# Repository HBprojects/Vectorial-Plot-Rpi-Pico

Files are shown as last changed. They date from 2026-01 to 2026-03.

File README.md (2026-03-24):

# Vectorial Reconstruction of an Electric Heart Vector in Saline Solution
This project implements a minimal analog front-end and software reconstruction algorithm to track a dipole vector immersed in saline solution. Drawing from the Einthoven triangle and its bipolar leads, maps electric potential to a real-time vectorial representation, similar how ECG devices take cardiac signals.
<p align="center">
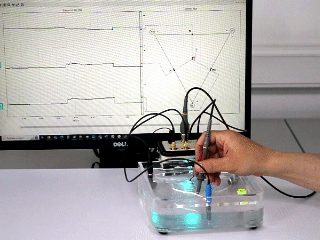
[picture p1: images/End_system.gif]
  
  
## 1. Motivation and context
The conduction and acquisition of biopotentials are non-observable phenomena, mastering these concepts typically requires a deep dive into abstract physiological theory. This project provides a tangible, real-time bridge between theory and practice.
By measuring potential differences induced by a hand probe within a conductive saline medium, this software calculates and graphically reconstructs a single dipole orientation and magnitude in real time. This approach transforms invisible electrical fields into an intuitive visual format.
## 2. System Overview
The physical setup mimics a standard **three-lead frontal plane EKG configuration** (RA, LA, LL) within a controlled environment.
### 2.1 Physical Configuration
- **The Medium:** A 500mL container filled with a 0.9% saline solution or a salt-water mixture.
- **The Electrodes:** Three terminal electrodes, which can be made from peeled wire, are placed in an equilateral triangle around the perimeter of the container.
- **Peripheral Spacing:** Peripheral electrodes are ideally separated by 120 to 150 mm.
### 2.2 The Dipole Source
- **Anode:** A wire is placed at the center of the container with a small exposed portion. This allows the system to show positive and negative voltages at the center of the projection lines.
- **Cathode (Probe):** An oscilloscope probe serves as the hand movable electrode. A wire with a 300Ω series resistor can also be used for testing.
- **Power:** The system is powered with 5V DC relative to the central terminal. This configuration is specifically chosen to minimize cathode corrosion within the electrolytic solution.
### 2.3 Data Acquisition & Processing
While high-performance differential ADCs or microcontrollers like the NXP K64F are recommended for precision, this repository provides a setup for easy testing using a Raspberry Pi Pico. The signal is pre-amplified by instrumentation amplifiers, biased at mid-supply, and processed in software to remove offset and gain before being streamed as comma-separated numeric values for real-time plotting.
## 3. Repository Structure
```text
project/
│
├── firmware/
│   └── Vecto_pico.py              # Micropython program for Raspberry Pi Pico
│   └── demo_signal_pico.py		   #Fast test of Pico board and graph program
│   └── VECTO2_MK64F12_Project.hex # Binary file for FRDM K64F board
├── images/	
├── kicad/				             # Circuit files
├── software/
│   └── vecto_graph.py		 	    # Real-time plotting via Python and Matplotlib
└── README.md
```
## 4. Implementation Architecture
The system is designed to provide high-fidelity signal acquisition while maintaining a simple interface for real-time analysis.
- **Analog Front-End;** True differential sensing to capture signals before ADC quantization.
- **Digitization;** The Raspberry Pi Pico ADC serves as a digitizer. A more reliable and precise version using the NXP K64F microcontroller.
- **Visualization;** A Python sketch allows for interaction with the circuit and real-time signal plotting.
### 4.1 Components
The following components are required to replicate the basic experimental setup:
| Qty | Component | Notes |
|:---:|:---|:---|
|2| INA128 instrumentation amplifiers | See schematic |
|1| Raspberry Pi Pico V2 | 
|12| Resistors (1% preferred) | See schematic |
|4| Decoupling and filtering capacitors | See schematic |
|1| Isolated 5V Lab power supply | Also tested with SWM12-5-N adapter |
|1| 1X Oscilloscope probe | Also tested with a wire with 300 ohm series resistor |
|1| 500mL 0.9% saline solution | Also tested with salt-water mixture |
|1| Low profile plastic container | Peripheral electrodes separated between 120 to 150 mm|
---
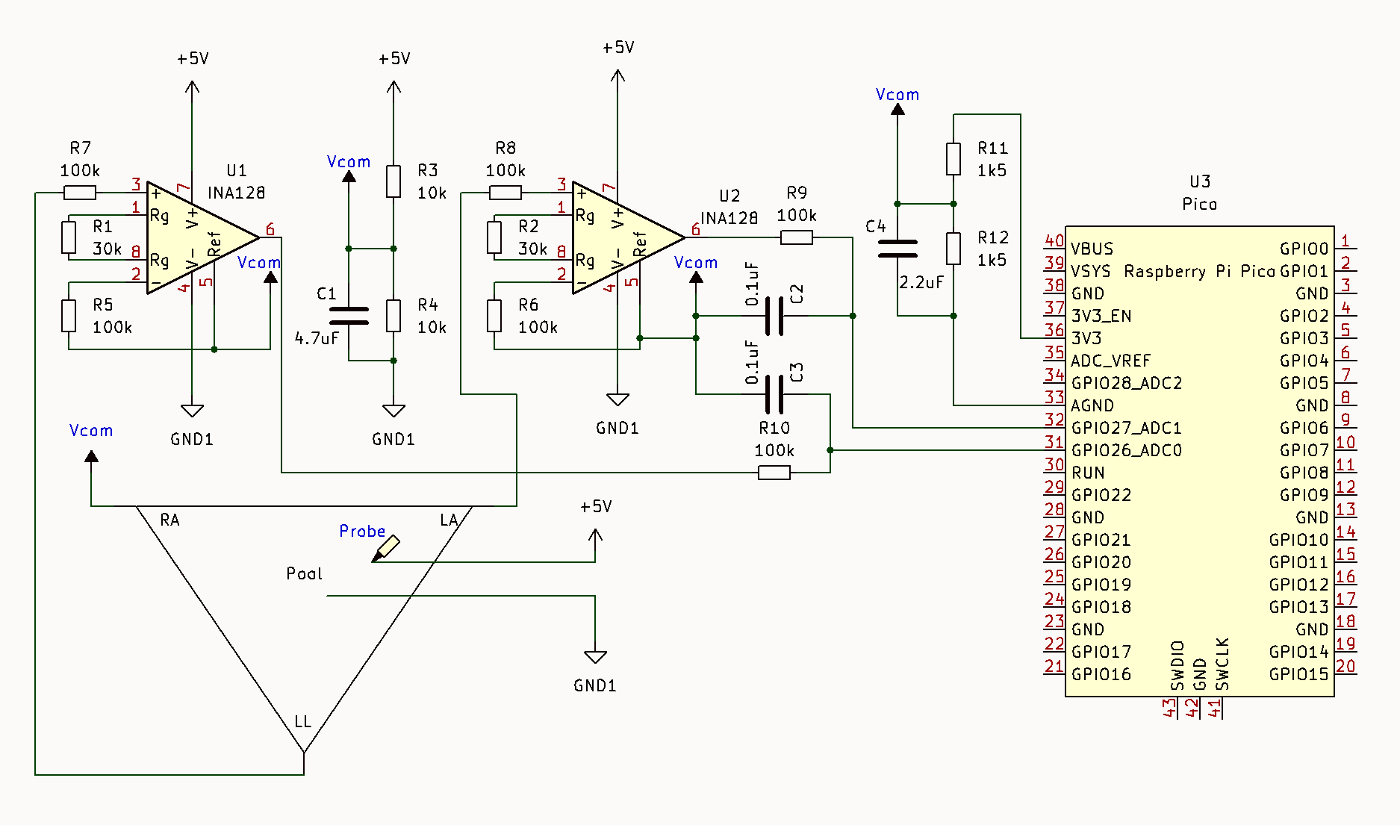
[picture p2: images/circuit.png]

The following components are required to replicate the improved performance setup version based on (FRDM K64F board):
| Qty | Component | Notes |
|:---:|:---|:---|
|1| MAX6018 | Voltage reference | See schematic |
|1| MAX4053 | Multiplexer | See schematic |
|1| K64F Microcontroller | FRDM K64F Board |
|-| Decoupling and filtering capacitors | See schematic |
|1| power supply | SWM12-5-N adapter |
|1| ITX0505SA | DC-DC Converter |
|1| 1X Oscilloscope probe | Also tested with a wire with 300 ohm series resistor |
|1| 500mL 0.9% saline solution | Also tested with salt-water mixture |
|1| Acrylic plastic container | Peripheral electrodes separated between 120 to 150 mm|
---

### 4.2 Power Domains & Grounding
 - **Analog Domain**: INA128 powered from an **isolated 5V source**, Two operational amplifiers couple the LI and LII signals, by the Kirchoff’s voltage law LI+LIII=LII, which allows the system to calculate LIII, However the measurement of the third value allows the system to reduce the zero error.
 - **Digital domain**: Pico powered from USB- Improves noise immunity
 - **Reference coupling**: Single-point connection between:
 - INA128 `REF`5 V mid-voltage 
 - Pico 3.3V mid-voltage
This architecture minimizes ground loops and digital noise injection and centers ADC measurements.
### 4.3 Gain Configuration
INA128 gain is defined by:
$G = 1 + 50kΩ/R_G$
Current implementation:
- Gain ≈ **2.6**
- Optimized for ±0.3 V input signals
- Ensures ADC full-scale utilization without saturation
## 5. Firmware (Raspberry Pi Pico_MicroPython, hex file for K64F)
Two independent programs facilitate the implementation of the system.
- **vecto_pico.py** Streams three values ( LI. LII, LIII) obtained by the ADC.
- **demo_signal_pico.py** A sketch for rapid testing of communication and visualization program. Load the sketch to the Raspberry Pi Pico and a demo signal are streamed by the USB port to the visualization program.
### 5.1 Acquisition Strategy
- Two ADC channels sampled independently
- Oversampling with averaging
- Offset removal is managed via a shared reference.
### 5.2 Pico Firmware Code
```python
from machine import ADC
import time
# --- Configuration ---
VREF = 3.3
VMID = 1.4 #VREF/2 A bit less improve zero error.
GAIN = 2.6 #The analog gain in the instrumentation amplifier.
```
- Analog and digital supplies are isolated except for a **shared reference point**
- Very high input impedance → suitable for **low-power sensors**
- To change the signal register speed, press ‘m’ in the keyboard in the graphic program.
- The time scale is the same, that allows to draw waveforms more easy, for example a wave of 100mS period can be draw in 1S.
### 5.3 Data Output Format
Each serial line contains three comma-separated floating-point values: 
Raspberry Pi Pico: DI, DII, DIII.
K64F: DI, DII, DIII,Calculated AvR, Calculated AvF, Calculated AvL, Sample_time (mS).
```text
Example:
Raspberry Pi Pico: 
0.01234, -0.01022,1.81200
K64F: 
0.01234, -0.01022,1.81200,0.02545,0.78459,0.89156,0.84100
```
### 5.4 Demo signal program.
The program continuously streams a previously recorded ECG signal to the host graphical application through a USB serial port, allowing the firmware and host program to be tested without difficulty.
```python
# --- Parameters ---
SCALE_FACTOR = 0.000435 #This value converts the table values to mS
TARGET_POINTS = 680 #Adjust the time scale, 
```
The **target points** parameter keeps the ECG signal within a normal scale, typically ranging between 600 and 700 points. This is because the table contains a fixed number of points, which must be adapted to the amount of data that can be effectively represented graphically.
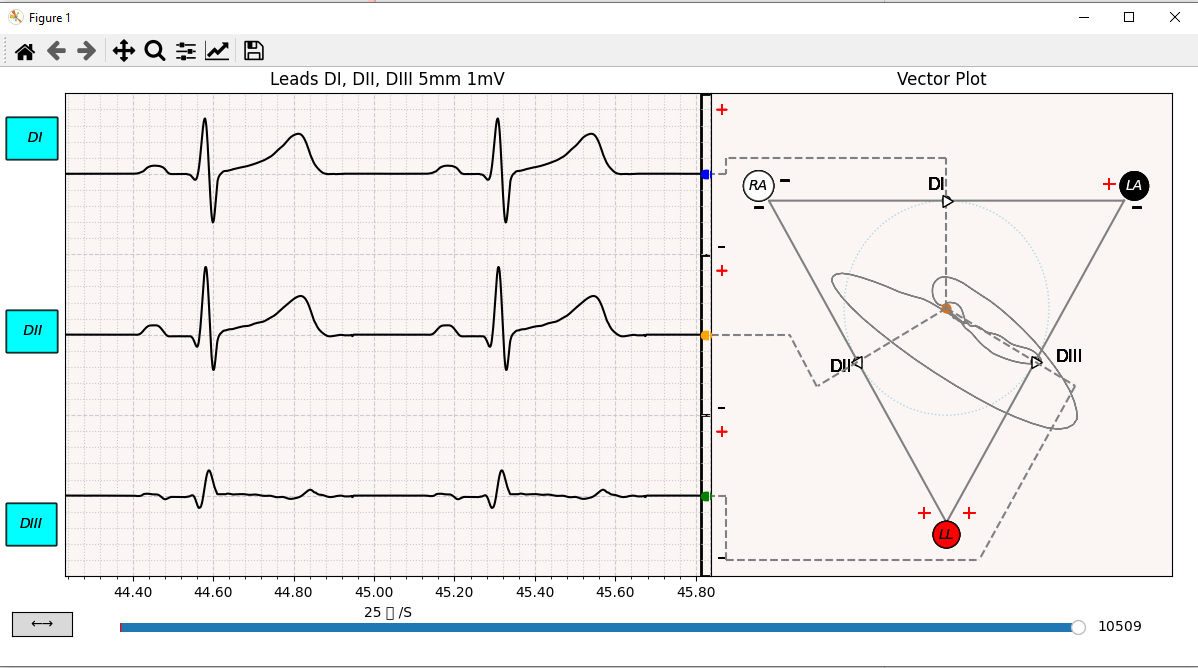
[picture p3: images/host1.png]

### 5.5 Animation Speed vs. Time Scale
The delay time parameter allows you to slow down the signal animation to observe vector behavior more clearly.
- **Animation Speed:** Adjusting the delay does not change the actual time scale of the signal.
- **Accuracy:** For example, if a signal period is 0.75s, the scale will always display 0.75s regardless of the animation speed. This ensures that any captured or "printed" signal maintains its physical temporal accuracy.
```python
# --- Parameter ---
# Adjust this value (e.g., between 5-50) to slow the animation
utime.sleep_ms(5)
``` 
### 5.6 Getting Started
- Flash the Pico: Use Thonny to upload the demo_signal_pico.py sketch to your Raspberry Pi Pico.
- Configure the Host: Open the host script vecto_graph.py in a text editor and update the serial port number to match your Raspberry Pi Pico’s port.
- Updating Parameters: To apply new changes to the Pico, close the host program, update the code, and re-upload the sketch to the board.
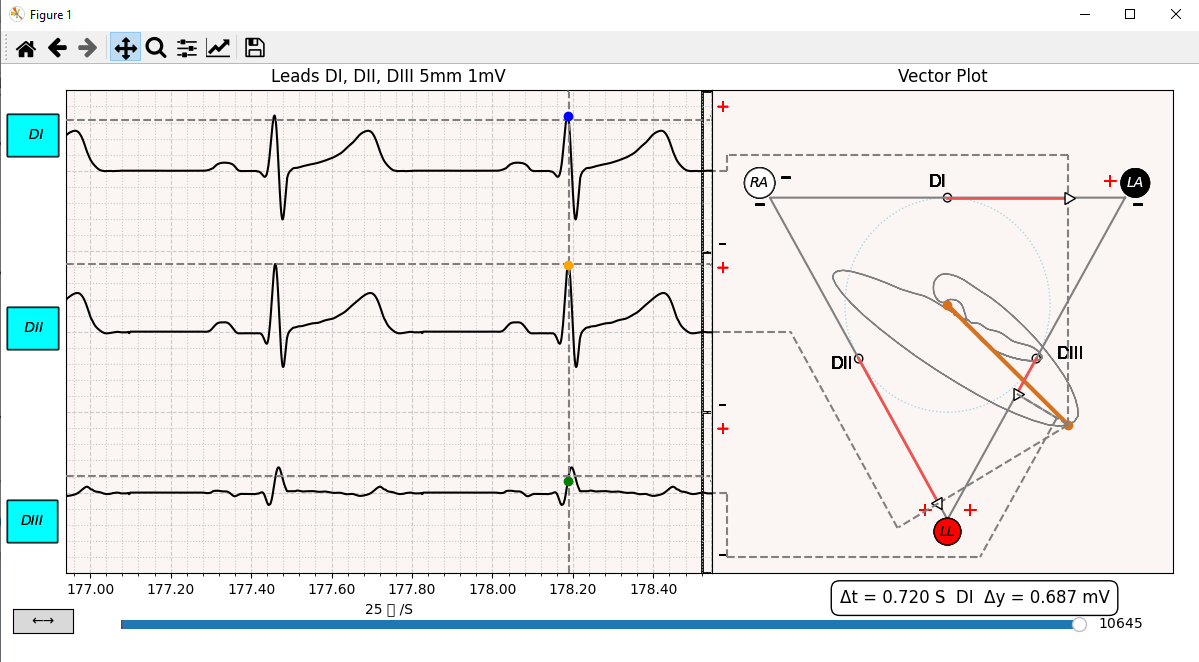
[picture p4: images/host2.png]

### 5.7. Interacting with the Graph
- **Pause:** Press the "P" key while the signal is running to pause the animation.
- **Inspection:** Move your mouse over the signal profile. A crosshair will track your pointer, and the vector graph will update dynamically to reflect the values at that specific point.
- **Measurement:** Click anywhere on the three signals to set a reference point.
 - The bottom-right corner of the screen will display two numerical values.
 - Click a second time at a different location to calculate the amplitude and time lapse (Δt) between the two selected points.

## 6. Host-Side Visualization (Python)
### 6.1 Features
- High-baud serial acquisition and circular buffering for real-time plotting.
- Data history retention for 5 seconds with a scrollable timeline.
- Interactive controls: Pause/resume via keyboard ('p') and grid-based signal inspection.
- Multi-channel and vector visualization.
### 6.2 Implementation
Using pyserial, numpy, matplotlib, and FuncAnimation. It continuously reads the serial output and maintains a fixed-length real-time window for inspection.
The script:
- Continuously reads Pico serial output
- Maintains a fixed-length real-time window
- Allows retrospective inspection of stored data
- Supports interactive control via keyboard
## 7. Experimental Performance
Parameter	Observed
Input range	±0.3 V
CMRR	~90 dB (INA128)
Effective resolution	~10–11 ENOB
ADC sampling stability	Good (with averaging)
Noise sensitivity	Dominated by reference stability
## 8. Limitations
- Pico ADC is not differential
- Overall ENOB limited by RP2040 ADC
- INA128 is not rail-to-rail amplifier.
- Requires careful reference grounding
Adding DC-DC converter before the polarization electrodes and a precision voltage reference improves the noise reduction the K64F firmware includes 60Hz Notch filter.
## 9. Next Steps
The second part of this project consists of:
Python host-side excecutable code.
Bioamplified version.
Zero correction and central terminal software.
This will be documented separately.
## 10. Authors
- Profesor Diana Patricia Amador PhD.
- Profesor William Ricardo Rodríguez PhD.
- Hernan Bernal Mechanical Designer.

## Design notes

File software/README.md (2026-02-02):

# Real-Time Serial ECG Visualization Software
This software acquires 3-channel ADC signals (Simulated ECG) from a microcontroller over a serial connection, displays them in real time, allows pause/scroll/inspection, computes a heart vector, and saves synchronized data for offline analysis.
Designed for research and laboratory use.
## 1. Quick Start
Requirements
-	Python 3.x
-	NumPy
-	Matplotlib
-	PySerial
-	Microcontroller streaming ADC data via serial
### Run
python python vecto_graph.py
## 2. Critical Configuration (Must Read)
### 2.1 Serial Port
Set the correct serial port before running:
ser_port = 'COM10'  # Change to your port
Examples:
- Windows: COM3
-	Linux: /dev/ttyUSB0
-	macOS: /dev/cu.usbmodemXXXX
### 2.2 Expected ADC Channels (Firmware Match)
Inside read_serial_data() (≈ line 484):
if len(values) == 3:
-	Raspberry Pi Pico firmware → == 3
-	K64F firmware → replace with > 4
This must match the firmware output, or data parsing will fail.
## 3. Keyboard Controls (Core Usage)
| Key | Action | Notes |
|:---:|:---|:---|
|1| Isolated 5V Lab power supply | Also tested with SWM12-5-N adapter |
|a| Start ADC streaming | Active by default |
|p|	Pause / resume acquisition | Enables scrolling through previously recorded data |
|← / →|	Scroll data | (paused only) |
|j|	Save visible data window | numpy format .npy (paused only) |
|r|	Start recording | Only in K64F firmware, need a MicroSD card |
|d|	Dumie recorded signal | (Not paused) |
|z|	Zero offsets |In K64F firmware only |
|t|	Tune / calibration command | Only in K64F firmware |
|m|	Change actual speed | Fast by default |
## 4. Core Function (Must Understand)
on_key(event)
Handles all user interaction:
-	Controls pause/resume logic
-	Sends commands to the microcontroller
-	Enables data scrolling
-	Extracts, scales, and saves 3-channel data to .npy
This function defines how the user operates the software.
## 5. Typical Workflow
-	Set serial port
-	Connect microcontroller
-	Run the script
- Press p to pause
- Scroll and inspect data
- Press j to save
- Press p to continue in real time mode
- Press d to stream the demo signal (firmware)
## 6. Performance Functions
-	init() – Initializes figures, axes, buffers, and event handlers.
-	format_func() – Formats axis tick labels.
-	update_xspeed() – Changes plot scrolling speed.
-	update_slider() – Syncs slider limits with stored data.
-	onmove() – Tracks mouse movement over the plot.
-	plot_on_click() – Extracts data at a clicked point.
-	handle_resize() – Maintains layout on window resize.
-	calc_heart_vector() – Computes vector representation from 3 channels.
-	calc_per_points() – Computes values at a specific cursor position.
-	update_axs() – Updates plots during animation frames.
## 7. Data Output
Saved File
-	seem_ath20.npy. "seem_ath20" change the name as needed  in program line 352
-	Shape: (1500, 3) by default
- Columns: Channel 1, Channel 2, Channel 3
Saved when pausing (p) then (j).
## 8. Notes
•	Assumes synchronized multi-channel data
•	Timing depends on firmware sampling
•	Intended for experimental and research use

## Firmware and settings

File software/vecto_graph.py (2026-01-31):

import sys
import serial
import numpy as np
import matplotlib.pyplot as plt
from numpy import cos, sin, pi
import matplotlib.animation as animation
from matplotlib.widgets import Button
from matplotlib.widgets import Slider
from collections import deque
from matplotlib.backend_bases import MouseEvent
from matplotlib.patches import Rectangle
from matplotlib.ticker import MultipleLocator, FuncFormatter

ser_port = 'COM10'  # Replace with your serial port
baud_rate = 230400  # Increase the baud rate if possible
timeout = 0.1  # Non-blocking mode

# Create a serial connection
ser = serial.Serial(ser_port, baud_rate, timeout=timeout)

side_lines_color = 'black'#'white'
triangle_color = 'gray'#'orange'
x1_facecolor = '#FBF5F3'#'#FBF5F3' '#FBF5F3'
x2_facecolor = '#FBF5F3'#'#FBF5F3''#154F61'
proy_linesColor = 'gray'#'green'
# Define the circle radius
radius = 1
value1 = 0.0
value2 = 0.0
value3 = 0.0
x_pos = 0.0
y_pos = 0.0

offset1 = 150#-530
offset2 = 50#-570
offset3 = -50#10

# Calculate the side length of the equilateral triangle circumscribed around the circle
side_length = 2 * radius * np.sqrt(3)

# Define the number of data points to display in the real-time plot
max_data_points = 1500#was 1500
spd_idx = 1
paused = False
is_over_plot = False
on_click_flag = False
count_mouse_pos = 0
mouseXpos = 1
xm_val = 0
# Initialize NumPy arrays to store data
full_x_data = np.zeros(max_data_points)  # Dynamically grow as needed
D1_data = np.zeros(max_data_points)  # Dynamically grow as needed
D2_data = np.zeros(max_data_points)  # Dynamically grow as needed
D3_data = np.zeros(max_data_points)  # Dynamically grow as needed

# Initialize a circular buffer for real-time plotting
x_data = np.zeros(max_data_points)
y1_data = np.zeros(max_data_points)
y2_data = np.zeros(max_data_points)
y3_data = np.zeros(max_data_points)
index = 0

# Define the width ratio (left plot is 1.5 times wider than the right plot)
left_width = 1.4
right_width = 1
# Create the figure and subplots
fig, (ax1, ax2) = plt.subplots(1, 2, figsize=(12, 6), gridspec_kw={'width_ratios': [left_width, right_width]})
#fig, (ax1, ax2) = plt.subplots(1, 2, figsize=(16, 10))

fig.tight_layout()
fig.subplots_adjust(top=0.956, left=0.054)# Remove space between subplots
fig.subplots_adjust(wspace=0.0)# Remove space between subplots
fig.subplots_adjust(bottom=0.15)

line1, = ax1.plot([], [], label="DI", color='black')
line2, = ax1.plot([], [], label="DII", color='black')
line3, = ax1.plot([], [], label="DIII", color='black')
# Set plot labels
ax1.set_title("Leads DI, DII, DIII 5mm 1mV")

# Define the expected X, Y-axis range
y1_min, y1_max = -100, 200
x1_min, x1_max = 0, max_data_points
ax1.set_ylim(y1_min, y1_max)
ax1.set_xlim(x1_min, x1_max)
ax1.set_facecolor(x1_facecolor)
ax1.set_aspect('auto')

crosshair_h = ax1.axhline(color='gray', linestyle='--')  # Horizontal line
crosshair_i = ax1.axhline(color='gray', linestyle='--')  # Horizontal line
crosshair_j = ax1.axhline(color='gray', linestyle='--')  # Horizontal line
crosshair_v = ax1.axvline(color='gray', linestyle='--')  # Vertical line
crosshair_h.set_visible(False)
crosshair_i.set_visible(False)
crosshair_j.set_visible(False)
crosshair_v.set_visible(False)

last_point1, = ax1.plot([], [], 'bo')  # blue dot for DI
actual_point1, = ax1.plot([], [], 'bo')  # blue dot for DI
last_point2, = ax1.plot([], [], 'o', color='orange')  # dot for DII
actual_point2, = ax1.plot([], [], 'o', color='orange')  # dot for DII
last_point3, = ax1.plot([], [], 'go')  #dot for DIII
actual_point3, = ax1.plot([], [], 'go')  #dot for DIII

# Define the vertices of the equilateral triangle
# One side will be horizontal at the top
angles = np.deg2rad([60, 180, 300])  # Vertices of the equilateral triangle
triangle_x = side_length * np.cos(angles) / np.sqrt(3)
triangle_y = side_length * np.sin(angles) / np.sqrt(3)

# Adjust to make sure the top side is horizontal
# Rotate -30 degrees to make the top horizontal
rotation_angle = -30  # Degrees to rotate counterclockwise
rotation_matrix = np.array([
    [np.cos(np.deg2rad(rotation_angle)), -np.sin(np.deg2rad(rotation_angle))],
    [np.sin(np.deg2rad(rotation_angle)),  np.cos(np.deg2rad(rotation_angle))]
])
rotated_triangle = np.dot(rotation_matrix, np.vstack((triangle_x, triangle_y)))

# Close the triangle path
triangle_x = np.append(rotated_triangle[0], rotated_triangle[0][0])
triangle_y = np.append(rotated_triangle[1], rotated_triangle[1][0])

# Precompute triangle side vectors and lengths for projection calculations
triangle_vectors = [(triangle_x[j+1] - triangle_x[j], triangle_y[j+1] - triangle_y[j]) for j in range(3)]

# Create a slider for scrolling through the data
ax_slider = plt.axes([0.1, 0.05, 0.8, 0.03])
slider = Slider(ax_slider, '', 0, 1, valinit=0, valstep=4)
slider.set_active(False)  # Slider inactive until paused

x2_min, x2_max = -2.3, 2.2
y2_min, y2_max = -2.5, 2
ax1.set_aspect('equal', adjustable='datalim')  # Keep square aspect ratio
ax2.set_xlim(x2_min, x2_max)
ax2.set_ylim(y2_min, y2_max) 
ax2.set_title("Vector Plot")
ax2.set_anchor('C') 

# Remove y-axis number values but keep grid lines
ax1.tick_params(axis='y', which='both', length=0)  # Remove tick marks
ax1.set_yticklabels([])  # Remove y-axis labels but keep ticks for the grid

# Draw the circle with radius 1
circle = plt.Circle((0, 0), radius, color='lightblue', fill=False, linestyle='dotted')
ax2.add_artist(circle)

#Draw origin circles
circ1 = plt.Circle((0, 1), 0.04, color='black', fill=False)
ax2.add_artist(circ1)
circ2 = plt.Circle((0.866, -0.5), 0.04, color='black', fill=False)
ax2.add_artist(circ2)
circ3 = plt.Circle((-0.866, -0.5), 0.04, color='black', fill=False)
ax2.add_artist(circ3)

# Plot the equilateral triangle with the top side horizontal
ax2.plot(triangle_x, triangle_y, color=triangle_color, lw=1.5)

# Add text labels to the corners of the triangle
ax2.set_facecolor(x2_facecolor)
ax2.set_xticks([])  # Remove x-axis ticks
ax2.set_yticks([])  # Remove y-axis ticks
#for spine in ax2.spines.values():
#Signal rectangles 
rect1 = Rectangle((0.985,  0.666), 0.02, 0.333, transform=ax1.transAxes, edgecolor='black', lw=2, fill=True, facecolor=x1_facecolor)
ax1.add_patch(rect1)
rect2 = Rectangle((0.985, 0.333), 0.02, 0.333, transform=ax1.transAxes, edgecolor='black', lw=2, fill=True, facecolor=x1_facecolor)
ax1.add_patch(rect2)
rect3 = Rectangle((0.985, 0.0), 0.02, 0.333, transform=ax1.transAxes, edgecolor='black', lw=2, fill=True, facecolor=x1_facecolor)
ax1.add_patch(rect3)


# Draw lines from the center of the triangle sides to the perpendicular intersection points
midpoints = [((triangle_x[i] + triangle_x[i + 1]) / 2,
              (triangle_y[i] + triangle_y[i + 1]) / 2) for i in range(3)]

mid_x, mid_y = midpoints[1]
                #proy_lines[j+1].set_data([px-0.4, mid_x-0.562], [py-0.23 , mid_y])
x2_min, x2_max = -2.3, 2.2
new_line_1, = ax2.plot([x2_min, x2_min+0.77], [-0.25, -0.25], color=proy_linesColor, linestyle='--') 
new_line_2, = ax2.plot([x2_min + 0.15, 0.318], [y2_min + 0.15, y2_min + 0.15], color=proy_linesColor, linestyle='--') 

new_point_ax2 = ((y2_max - y2_min)/6)+y2_min
new_line_3, = ax2.plot([x2_min + 0.15, x2_min + 0.15], [y2_min + 0.15, new_point_ax2], color=proy_linesColor, linestyle='--') 
new_line_4, = ax2.plot([x2_min + 0.15, x2_min], [new_point_ax2, new_point_ax2], color=proy_linesColor, linestyle='--') 

new_point_ax2 = y2_max - ((y2_max - y2_min)/6)
new_line_5, = ax2.plot([x2_min + 0.15, x2_min + 0.15], [y2_max - 0.6, new_point_ax2], color=proy_linesColor, linestyle='--') 
new_line_6, = ax2.plot([x2_min + 0.15, x2_min], [new_point_ax2, new_point_ax2], color=proy_linesColor, linestyle='--') 
#proy_lines[j].set_data([x_pos, y2_min], [py + 0.4, py + 0.4])

#trace, = ax2.plot([], [], '.-', lw=1, ms=2, color='lightblue', zorder=1)
trace, = ax2.plot([], [], '-', lw=1, ms=2, color='gray', zorder=1)
vector, = ax2.plot([], [], 'o-', lw=3, color='#D8711C', zorder=2)
perpendicular_lines = [ax2.plot([], [], color=proy_linesColor, linestyle='--')[0] for _ in range(3)]
proy_lines = [ax2.plot([], [], color=proy_linesColor, linestyle='--')[0] for _ in range(5)]

#connector_lines = [ax2.plot([], [], 'o-', lw=3, color=side_lines_color)[0] for _ in range(3)]

connector_lines = []
for _ in range(3):
    line, = ax2.plot(
        [], [], 
        '-',                       # just a solid line
        lw=2,
        color=side_lines_color,
        marker=(3, 1, 0),          # a 3‑sided marker (triangle), 0° initial
        markevery=[-1],            # only draw that marker at the *last* point
        markersize=10,             # arrow‑head size
        markerfacecolor='white',    # fill color (change as you like)
        markeredgecolor=side_lines_color
    )
    connector_lines.append(line)

time_template = 'time = %.1fs'
time_text = ax2.text(0.05, 0.9, '', transform=ax2.transAxes)

ax_button = plt.axes([0.01, 0.05, 0.05, 0.04])  # Position: [x, y, width, height]
button1 = Button(ax_button, '←→')  # Create button

text_box1 = None
# Variables to store history of points
##history_x = []
#history_y = []
history_x = deque(maxlen=1500)  # Automatically discard older data when full
history_y = deque(maxlen=1500)#was 1500

def init():
    line1.set_data([], [])
    line2.set_data([], [])
    line3.set_data([], [])
    ax1.text(-0.07, 0.9, '  DI', style='italic', transform=ax1.transAxes,
             bbox={'facecolor': 'cyan', 'alpha': 0.5, 'pad': 10})
    ax1.text(-0.07, 0.5, ' DII', style='italic', transform=ax1.transAxes,
            bbox={'facecolor': 'cyan', 'alpha': 0.5, 'pad': 10})
    ax1.text(-0.07, 0.1, 'DIII', style='italic', transform=ax1.transAxes,
            bbox={'facecolor': 'cyan', 'alpha': 0.5, 'pad': 10})

    ax1.xaxis.set_major_formatter(FuncFormatter(format_func))
    ax1.set_xlabel('25  /S')

    ax1.xaxis.set_major_locator(MultipleLocator(50))  # Major ticks every 100 points
    ax1.xaxis.set_minor_locator(MultipleLocator(10))   # Minor ticks every 20 points
    ax1.yaxis.set_major_locator(MultipleLocator(50))  # Major ticks every 5 units
    ax1.yaxis.set_minor_locator(MultipleLocator(10))  # Minor ticks every 1 unit

    ax1.grid(which='major', color='#CCCCCC', linestyle='--')
    ax1.grid(which='minor', color='#CCCCCC', linestyle=':')
    ax1.grid(True, which='both')

    xc = float(((triangle_x[0]+triangle_x[1])/2)-0.1)
    yc = float(triangle_y[0])+0.1
    ax2.text(xc, yc, f'DI', fontsize=12, ha='center', color='black')
    #Left corner
    xc = float(triangle_x[0]+0.1)
    ax2.text(xc-0.25, yc, f'+', fontsize=14, ha='center', color='red')#red
    #ax2.text(xc, yc, f'+ LA', fontsize=12, ha='center', color='white')
    ax2.text(xc, yc, 'LA', fontsize=10, style='italic', ha='center', color='white',
         bbox={'facecolor': 'black', 'alpha': 0.5, 'boxstyle': 'circle', 'pad': 0.4})
    xc = float(triangle_x[0]+0.12)
    yc = float(triangle_y[0])-0.15
    ax2.text(xc, yc, f'-', fontsize=24, ha='center', color='black')
    xc = float(triangle_x[1]-0.1)
    yc = float(triangle_y[1])+0.1
    #Right corner
    ax2.text(xc + 0.25, yc, f'-', fontsize=24, ha='center', color='black')
    #ax2.text(xc, yc, f'RA -', fontsize=12, ha='center', color='black')
    ax2.text(xc, yc, 'RA', fontsize=10, style='italic', ha='center', color='black',
         bbox={'facecolor': 'white', 'alpha': 0.5, 'boxstyle': 'circle', 'pad': 0.4})
    yc = float(triangle_y[1])-0.15
    ax2.text(xc, yc, f'-', fontsize=24, ha='center', color='black')

    #ax2.text(xc, yc, f'-', fontsize=14, ha='center', color='black')
    xc = float(triangle_x[1]+0.7)
    yc = float(((triangle_y[1]+triangle_y[2])/2)-0.1)
    ax2.text(xc, yc, f'DII', fontsize=12, ha='center', color='black')
    xc = float(triangle_x[2]+1.2)
    yc = yc + 0.1
    ax2.text(xc, yc, f'DIII', fontsize=12, ha='center', color='black')
    #Low corner
    xc = float(triangle_x[2])
    yc = float(triangle_y[2])-0.15
    #ax2.text(xc, yc, f'+ LL +', fontsize=12, ha='center', color='red')
    ax2.text(xc, yc, 'LL', fontsize=10, style='italic', ha='center', color='black',
         bbox={'facecolor': 'red', 'alpha': 0.5, 'boxstyle': 'circle', 'pad': 0.4})
    ax2.text(xc - 0.22, yc + 0.18, f'+', fontsize=14, ha='center', color='red')
    ax2.text(xc + 0.22, yc + 0.18, f'+', fontsize=14, ha='center', color='red')

    yc = y2_max - 1.5
    ax2.text(x2_min + 0.1, y2_max - 0.2, f'+', fontsize=12, ha='center', color='red')
    ax2.text(x2_min + 0.1, yc, f'-', fontsize=18, ha='center', color='black')
    ax2.text(x2_min + 0.1, yc - 0.2, f'+', fontsize=12, ha='center', color='red')
    ax2.text(x2_min + 0.1, yc - 1.5, f'-', fontsize=18, ha='center', color='black')
    ax2.text(x2_min + 0.1, yc - 1.7, f'+', fontsize=12, ha='center', color='red')#red
    ax2.text(x2_min + 0.1, y2_min + 0.1, f'-', fontsize=18, ha='center', color='black')

    return [line1, line2, line3]

def format_func(value, tick_number):
    return f"{value / 250:.2f}"  # was 160Convert points to seconds

def update_xspeed(event):
    global spd_idx
    spd_idx += 1
    if spd_idx > 5:
        spd_idx = 1

def on_key(event):
    global paused, spd_idx
    if event.key == 'p':
        paused = not paused
        slider.set_active(paused)  # Enable or disable the slider
        if paused:
            ser.write('paus\n'.encode('ascii'))
            update_slider()
            new_val = len(full_x_data) - max_data_points
            slider.set_val(new_val)
            

            scroll_position = int(slider.val)
            start_idx = scroll_position
            end_idx = min(start_idx + max_data_points, len(full_x_data))
            # 1. Slice your individual data channels
            d1_slice = D1_data[start_idx:end_idx]
            d2_slice = D2_data[start_idx:end_idx]
            d3_slice = D3_data[start_idx:end_idx]
            
            d1_slice = d1_slice[:] - 150
            d2_slice = d2_slice[:] - 50
            d3_slice = d3_slice[:] + 50
            d1_slice = d1_slice[:] * 0.02
            d2_slice = d2_slice[:] * 0.02
            d3_slice = d3_slice[:] * 0.02
            
            # 2. Stack them horizontally to get shape (600, 3)
            combined_data = np.column_stack((d1_slice, d2_slice, d3_slice))
            # 3. Verify and Save
            print(combined_data.shape)
            np.save('seem_ath20.npy', combined_data)


        else:
            ser.write('adc0\n'.encode('ascii'))

        ax1.figure.canvas.draw_idle()

    if event.key == 'j':    
        if paused:
            print(combined_data.shape)  # Should show (600, 3)
            #np.save('my_data_3_channels.npy', combined_data)
            combined_data = np.column_stack((d1_slice, d2_slice, d3_slice))
            np.save('seem_ath20.npy', combined_data)


    if event.key == 't':    
        ser.write('tune\n'.encode('ascii'))
        print("tune")
    if event.key == 'z':    
        ser.write('z000\n'.encode('ascii'))
        print("zero")
    if event.key == 'a':    
        ser.write('adc0\n'.encode('ascii'))
        print("adc")
    if event.key == 'r':    
        ser.write('reca\n'.encode('ascii'))
        print("recording")
    if event.key == 'd':    
        ser.write('dumi\n'.encode('ascii'))
        print("Recorded signal")
    if event.key == 'm':    
        spd_idx += 1
        if spd_idx > 5:
            spd_idx = 1
    if event.key == 'right':
        if paused:
            # Move slider to the right
            update_slider()
            new_val = min(slider.val + 8, slider.valmax)
            slider.set_val(new_val)  # Update slider position
    elif event.key == 'left':
        if paused:
            # Move slider to the left
            update_slider()
            new_val = max(slider.val - 8, slider.valmin)
            slider.set_val(new_val)  # Update slider position        

    
def update_slider():
        # Update the slider range dynamically
        if len(full_x_data) > max_data_points:
            slider.valmax = len(full_x_data) - max_data_points
            slider.ax.set_xlim(0, slider.valmax)
            print(len(full_x_data))
        else:
            slider.valmax = 1
            slider.ax.set_xlim(0, 1)

def onmove(event):
    global is_over_plot, count_mouse_pos, mouseXpos, xm_val
    x_value = event.xdata
    if paused:#
        if event.inaxes == ax1:
            is_over_plot = True
            
            x_value = int(event.xdata)# - count_mouse_pos
            xm_val = x_value
            slide_idx = int(slider.valmax)
            #print(f"raw X: {x_value}")
            #print(f"count X: {count_mouse_pos}")
            #print(f"Full data : {len(full_x_data)}")
            xmouse_idx = count_mouse_pos - max_data_points - slide_idx
            if x_value is not None:
                # Calculate the local index in the visible data
                mouseXpos = x_value - xmouse_idx
                #print(f"calc X: {mouseXpos}")
                #print(f"len data=:{len(D1_data)}")
                
            crosshair_h.set_visible(True)
            crosshair_i.set_visible(True)
            crosshair_j.set_visible(True)
            crosshair_v.set_visible(True)
            

        else:
            is_over_plot = False

dt_old_val = 0.0
def plot_on_click (event):
    global on_click_flag, text_box1, dt_old_val
    if event.inaxes == ax1:  # If the mouse is within the plot area
        on_click_flag = True
        if event.ydata > 0:
            point = D1_data[mouseXpos]
        if event.ydata <= 0:
            point = D3_data[mouseXpos]
        print(f"Mouse clicked at: (x={mouseXpos}, y={point}), button={event.button}")


        if event.ydata > 100:
            point = D1_data[mouseXpos] - offset1
            txt_str = " DI  Δy = "
        elif event.ydata <= 0:
            point = D3_data[mouseXpos] - offset3
            txt_str = "DIII Δy = "
        else:
            point = D2_data[mouseXpos] - offset2
            txt_str = "DII  Δy = "
        point = point/50

        dt_val = (mouseXpos - dt_old_val)/940 #was 800
        dt_old_val = mouseXpos
        textBX_str = f"Δt = {dt_val:.3f} S {txt_str}{point:.3f} mV"  # Format text
        
        if text_box1 is None:
            text_box1 = fig.text(0.7, 0.1, textBX_str,
                                    fontsize=12, bbox=dict(facecolor='white', edgecolor='black', boxstyle='round,pad=0.5'))
        else:
            text_box1.set_text(textBX_str)  # 🔥 Only update the text, NOT redraw the box
                                    
        #fig.canvas.draw_idle()
        plt.pause(0.01)


def handle_resize(event):
    ax1.set_xlim(x1_min, x1_max)
    ax1.set_ylim(y1_min, y1_max)
    ax1.grid(which='both')
    ax2.set_xlim(x2_min, x2_max)
    ax2.set_ylim(y2_min, y2_max)
    ax2.set_anchor('C')

# Function to read serial data
def read_serial_data():
    global value1, value2, value3, x_pos, y_pos, full_x_data, D1_data, D2_data, D3_data, y1_data, y2_data, y3_data, index, count_mouse_pos
    read_count = 0  # Limit the number of reads per frame
    idx = 0   
    while ser.in_waiting and read_count < 40:#enable for not delaya real time plot in fast serial baud rate
        raw_data = ser.readline()
        #data = data[11:]#to remove bad first character
        data = raw_data.decode('utf-8', errors='ignore').strip()
        idx += 1
        try:
            values = data.split(',')
            if len(values) == 3: #> 4:#4 for k64f
                value1 = float(values[0])
                value2 = float(values[1])
                value3 = float(values[2])
                #print(f"data: {value1} , {value2}, {value3}")
                #print(value1 + value2 + value3)
                '''
                value1 = value1 + 78
                value2 = value2 -30 #invert
                value3 = value3 - 48
                '''
                value1 = (value1 / 3) #+ 0.001
                value2 = (value2 / 3) #- 0.001
                value3 = (value3 / 3) #- 0.001
            if idx >= spd_idx:
            
                radius, angle = calc_heart_vector(value1, value2, value3)
                
                value1 = (value1 * 9) + offset1#+ 150
                value2 = (value2 * -9) + offset2
                value3 = (value3 * 9) + offset3

                if radius is None or angle is None:
                    return []  # No valid data received

                # Calculate the current x, y position
                x_pos = radius * np.cos(angle)
                y_pos = radius * np.sin(angle)
                
                # Update history
                history_x.append(x_pos)
                history_y.append(y_pos)
            
                new_x_value = full_x_data[index - 1] + 1 if index > 0 else 0
                # Update full_x_data and D1_data
                if index < len(full_x_data):
                    full_x_data[index] = new_x_value
                    D1_data[index] = value1
                    D2_data[index] = value2
                    D3_data[index] = value3
                else:
                    full_x_data = np.append(full_x_data, new_x_value)
                    D1_data = np.append(D1_data, value1)
                    D2_data = np.append(D2_data, value2)
                    D3_data = np.append(D3_data, value3)

                y1_data[index % max_data_points] = value1
                y2_data[index % max_data_points] = value2
                y3_data[index % max_data_points] = value3
                index += 1
                count_mouse_pos += 1
                idx = 0
        except ValueError:
            print(f"Ignored invalid data: {data}")
        read_count += 1
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

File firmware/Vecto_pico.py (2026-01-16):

from machine import ADC
import time

# --- Configuration ---
ADC0_PIN = 26          # GPIO26 = ADC0
ADC1_PIN = 27          # GPIO27 = ADC1

VREF = 3.3
VMID = 1.1
GAIN = 2.6
ADC_MAX = 4095

adc0 = ADC(ADC0_PIN)
adc1 = ADC(ADC1_PIN)

def read_adc_voltage(adc, samples=8):
    acc = 0
    for _ in range(samples):
        acc += adc.read_u16() >> 4   # 12-bit value
    adc_raw = acc / samples

    v_adc = (adc_raw / ADC_MAX) * VREF
    v_diff = (v_adc - VMID) / GAIN

    return v_diff


# --- Main loop ---
while True:
    v0 = read_adc_voltage(adc0)
    v1 = read_adc_voltage(adc1)
    v3 = (v1 - v0)*-100
    v2 = (v1 - 0.31)*-100
    v1 = (v0 - 0.30)*-100
    

    # IMPORTANT: only numbers, comma-separated
    print("{:.5f},{:.5f},{:.5f}".format(v1, v2, v3))

    time.sleep(0.005)   # ~50 Hz (ideal for Thonny Plotter)
